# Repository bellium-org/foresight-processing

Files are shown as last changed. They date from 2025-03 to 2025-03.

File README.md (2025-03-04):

# Foresight Processing

## Overview
The processing board is responsible for the main processing of the vibration analysis. On board is the ATmega328pb microcontroller, RFM95W LoRa transceiver and ADXL362 accelerometer. In addition there is a NMOS low side switch to turn of the RFM95W and ADXL362 when they are not needed to save power consumption.

## Table of Contents

- [Hardware Setup](#hardware-setup)
- [Imporant Notice](#important-notice)

### Hardware Setup

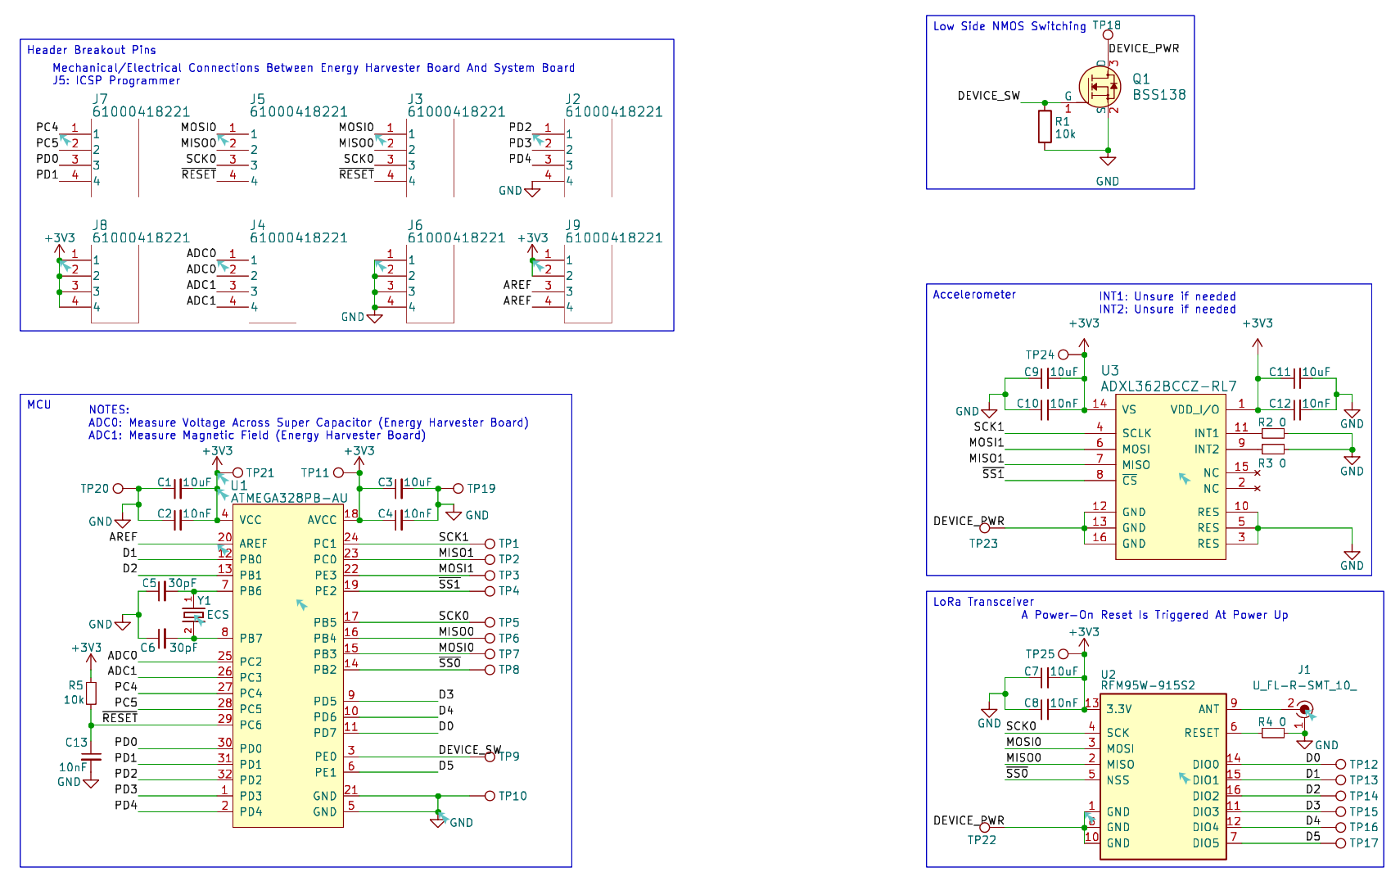
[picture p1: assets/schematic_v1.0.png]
Description of image


### Important Notice
- All required components used in this project can be located in the components folder. 
- To add these components into your workspace please follow the instructions from given from each of the individual components. 
- Ensure the digikey submodule is initialise and follow the README to set this up.

## Authors
- Nathan Nguyen

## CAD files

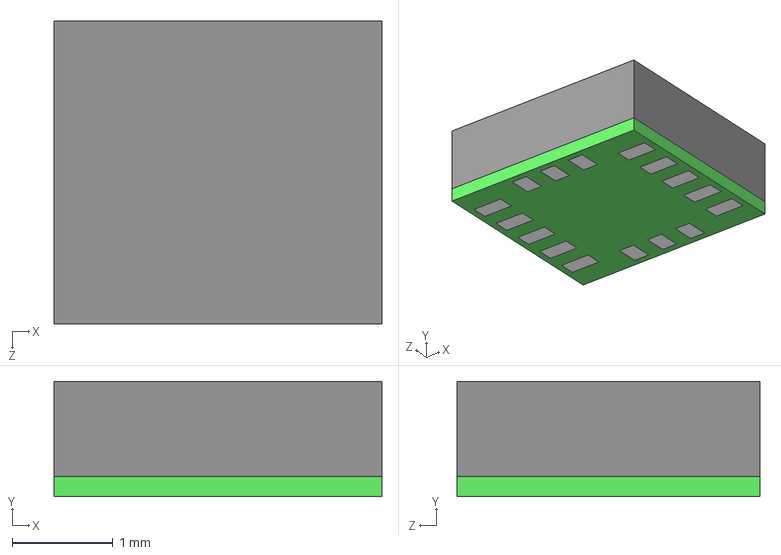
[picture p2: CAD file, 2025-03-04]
components/foresight/ADXL362BCCZ_RL7/ADXL362BCCZ-RL7.step
3.25 x 1.14 x 3.00 mm

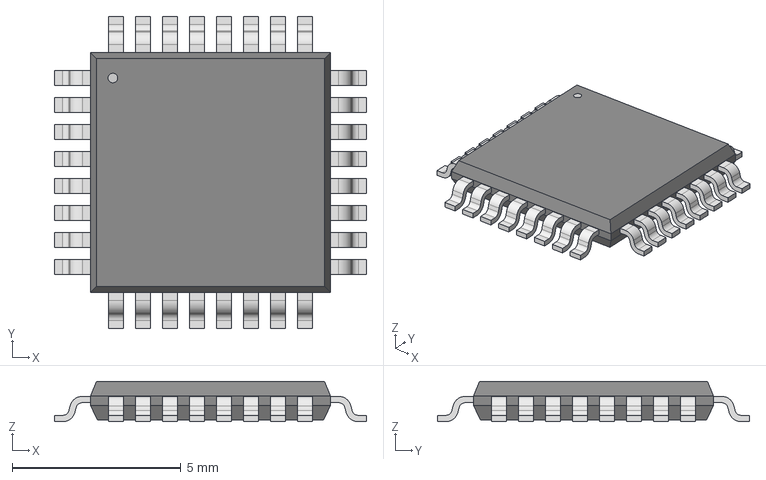
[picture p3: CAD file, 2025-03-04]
components/foresight/ATMEGA328P_AU/TQFP32_32A_MCH.step
9.25 x 9.25 x 1.20 mm

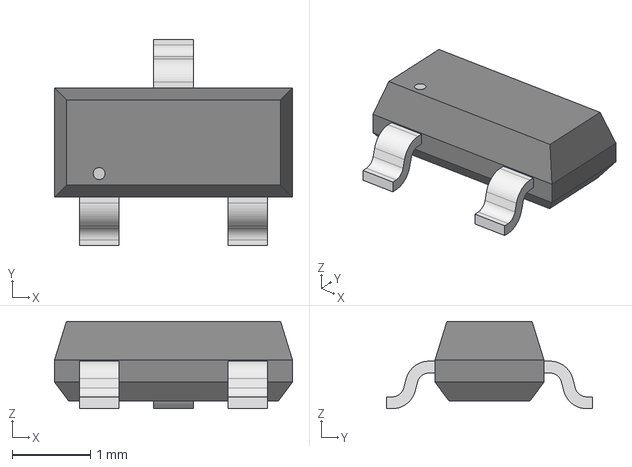
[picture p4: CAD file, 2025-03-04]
components/foresight/BSS138/SOT-23_3L_ONS.step
3.05 x 2.64 x 1.12 mm

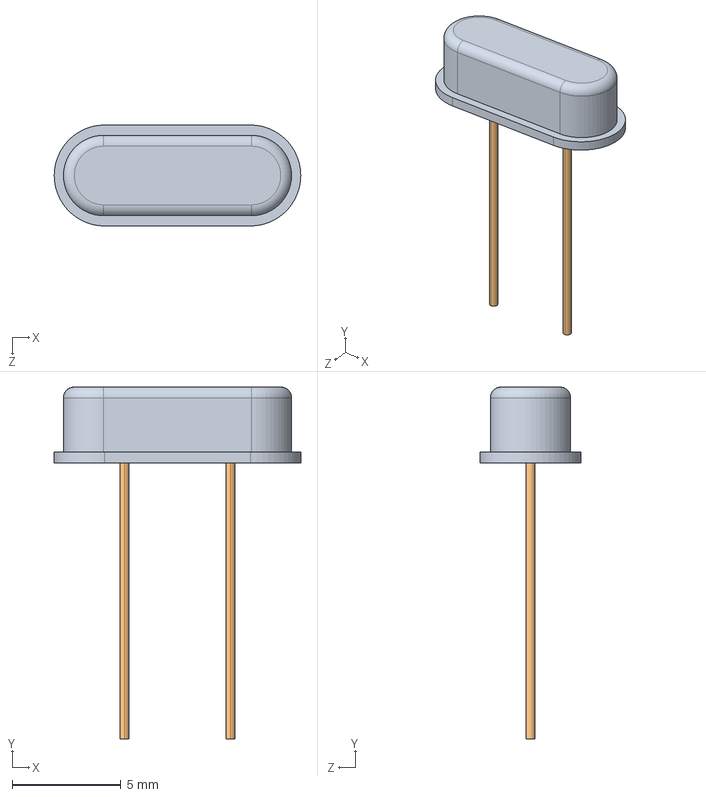
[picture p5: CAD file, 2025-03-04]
components/foresight/ECS_160_S_4/ECS-160-S-4.step
11.4 x 16.2 x 4.65 mm

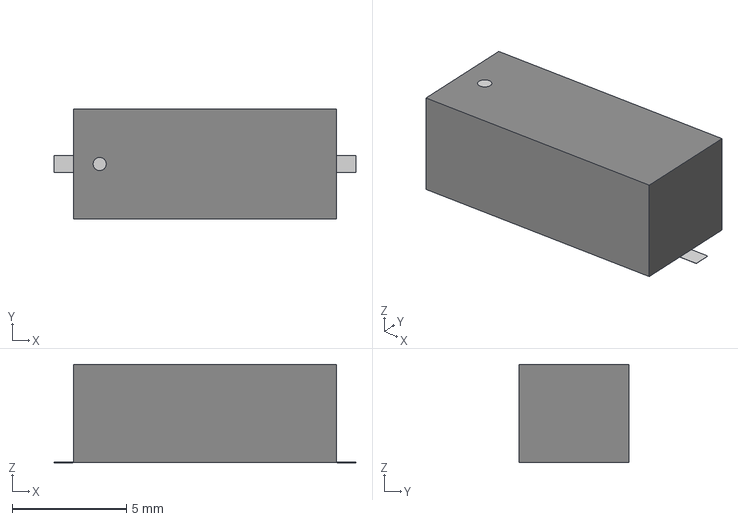
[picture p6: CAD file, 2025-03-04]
components/foresight/ECS_80_18_5PX_TR/CRYSTAL_ECS-80-18-5PX-TR_ECS.step
13.2 x 4.80 x 4.29 mm

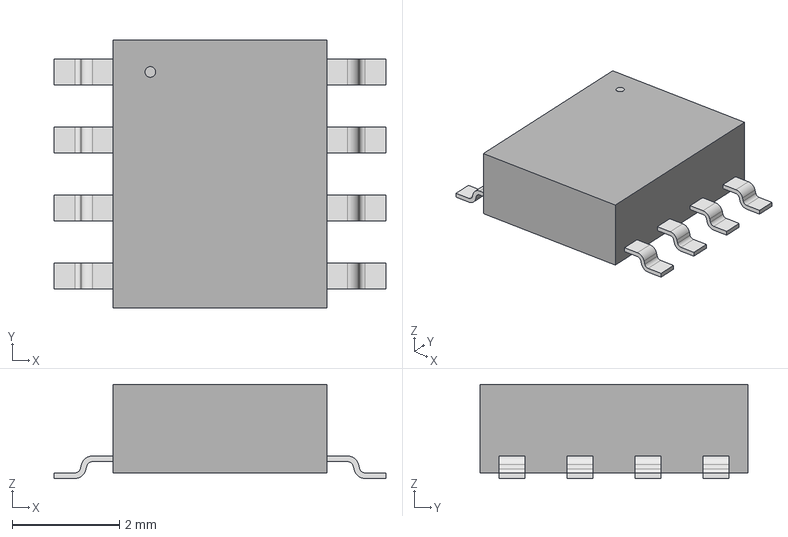
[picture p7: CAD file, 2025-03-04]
components/foresight/LT1763CS8_5_TRPBF/SO-8_S_LIT.step
6.20 x 5.00 x 1.75 mm

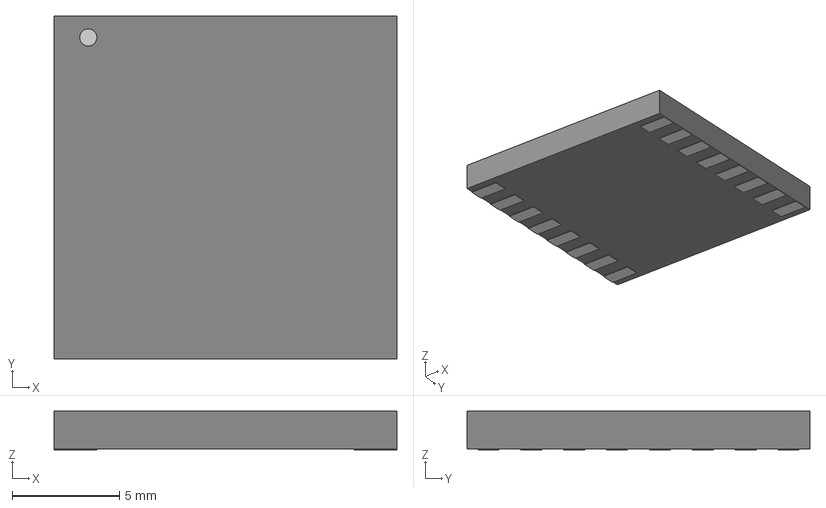
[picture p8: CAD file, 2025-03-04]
components/foresight/RFM95W_915S2/IC16_RFM95W-915S2_RFS.step
16.0 x 16.0 x 1.81 mm

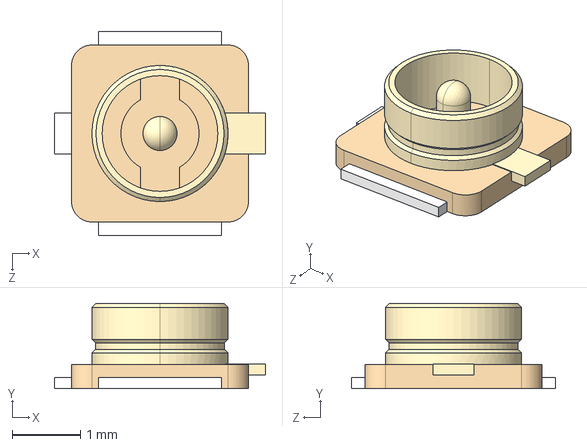
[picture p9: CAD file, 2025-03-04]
components/foresight/U_FL_R_SMT_10_/U.FL-R-SMT_10_.step
3.10 x 1.25 x 3.00 mm

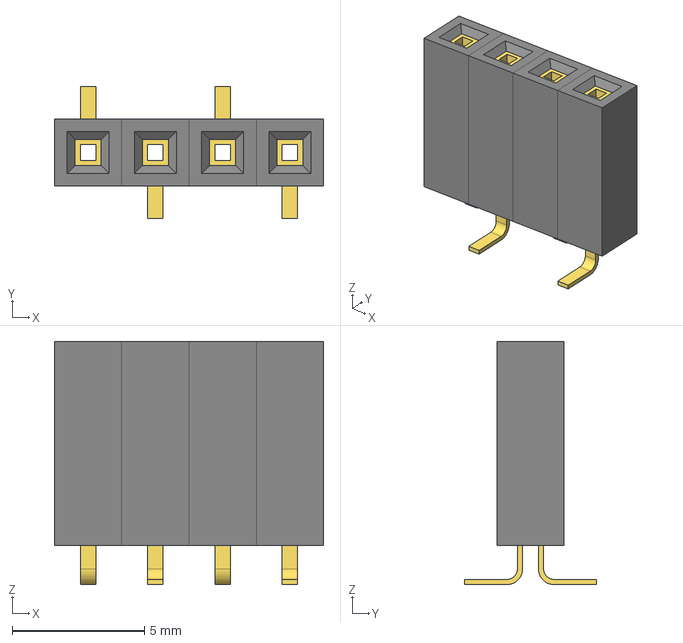
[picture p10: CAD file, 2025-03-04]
components/foresight/61000418221/61000418221_WRE.step
10.2 x 5.00 x 9.19 mm

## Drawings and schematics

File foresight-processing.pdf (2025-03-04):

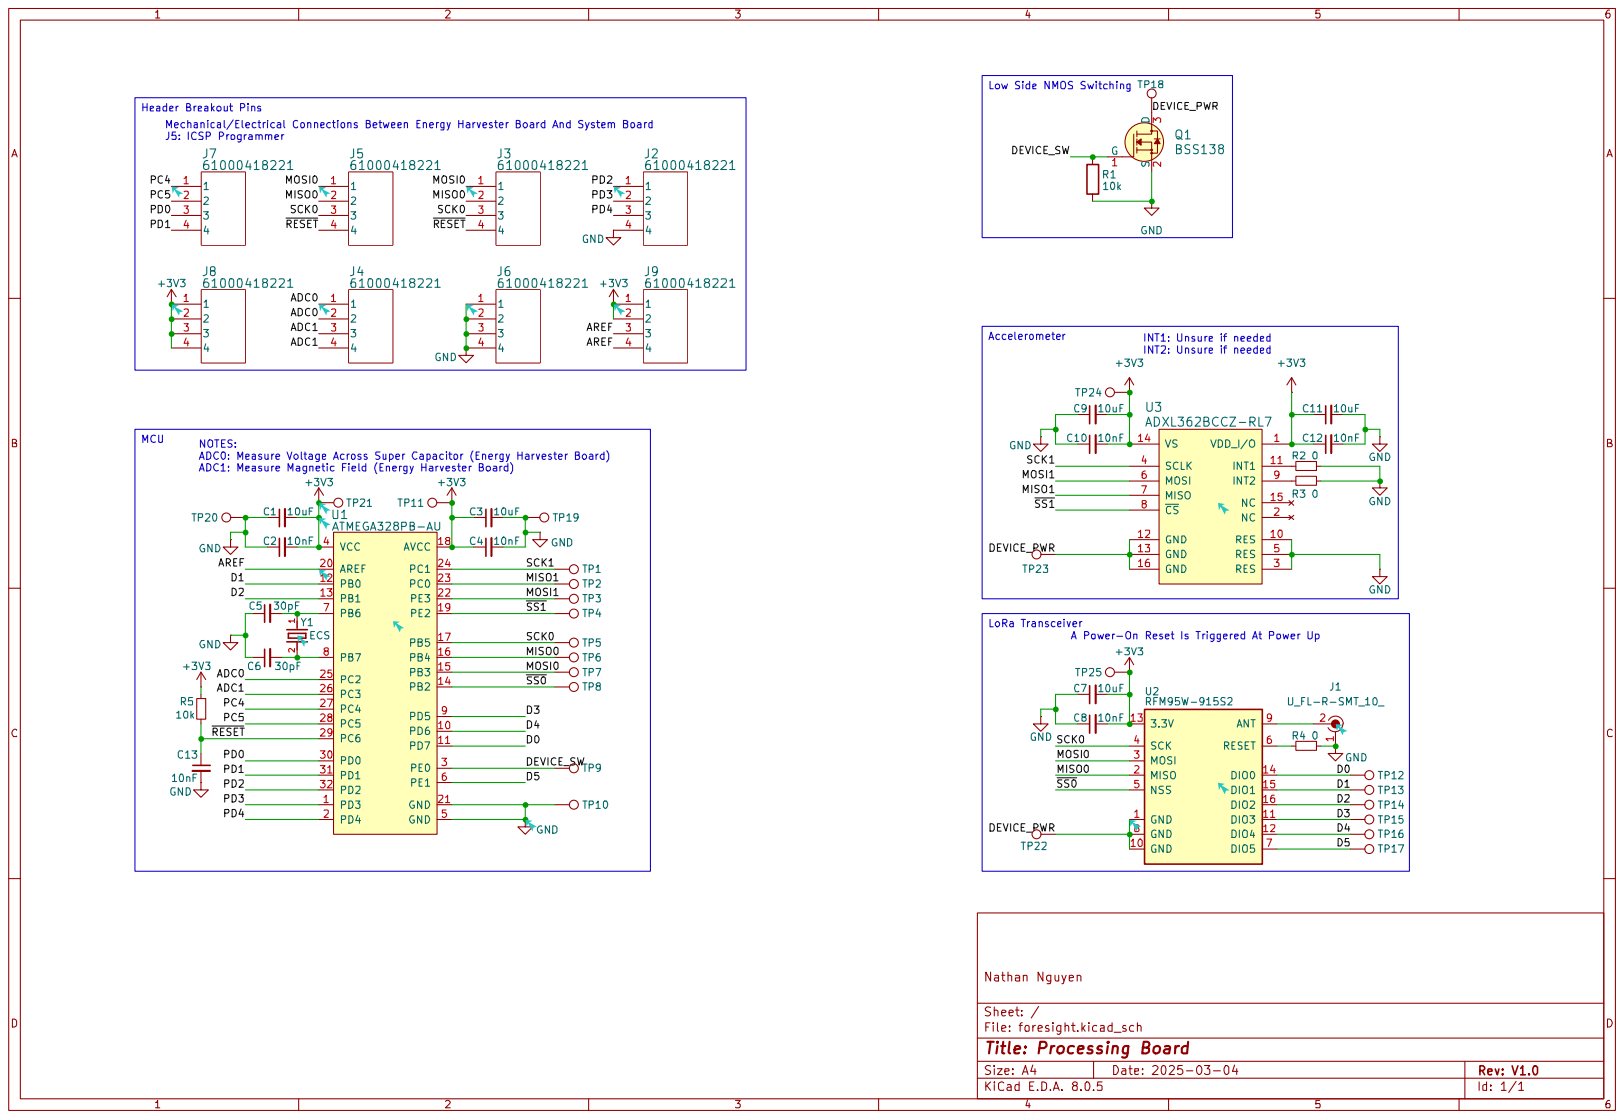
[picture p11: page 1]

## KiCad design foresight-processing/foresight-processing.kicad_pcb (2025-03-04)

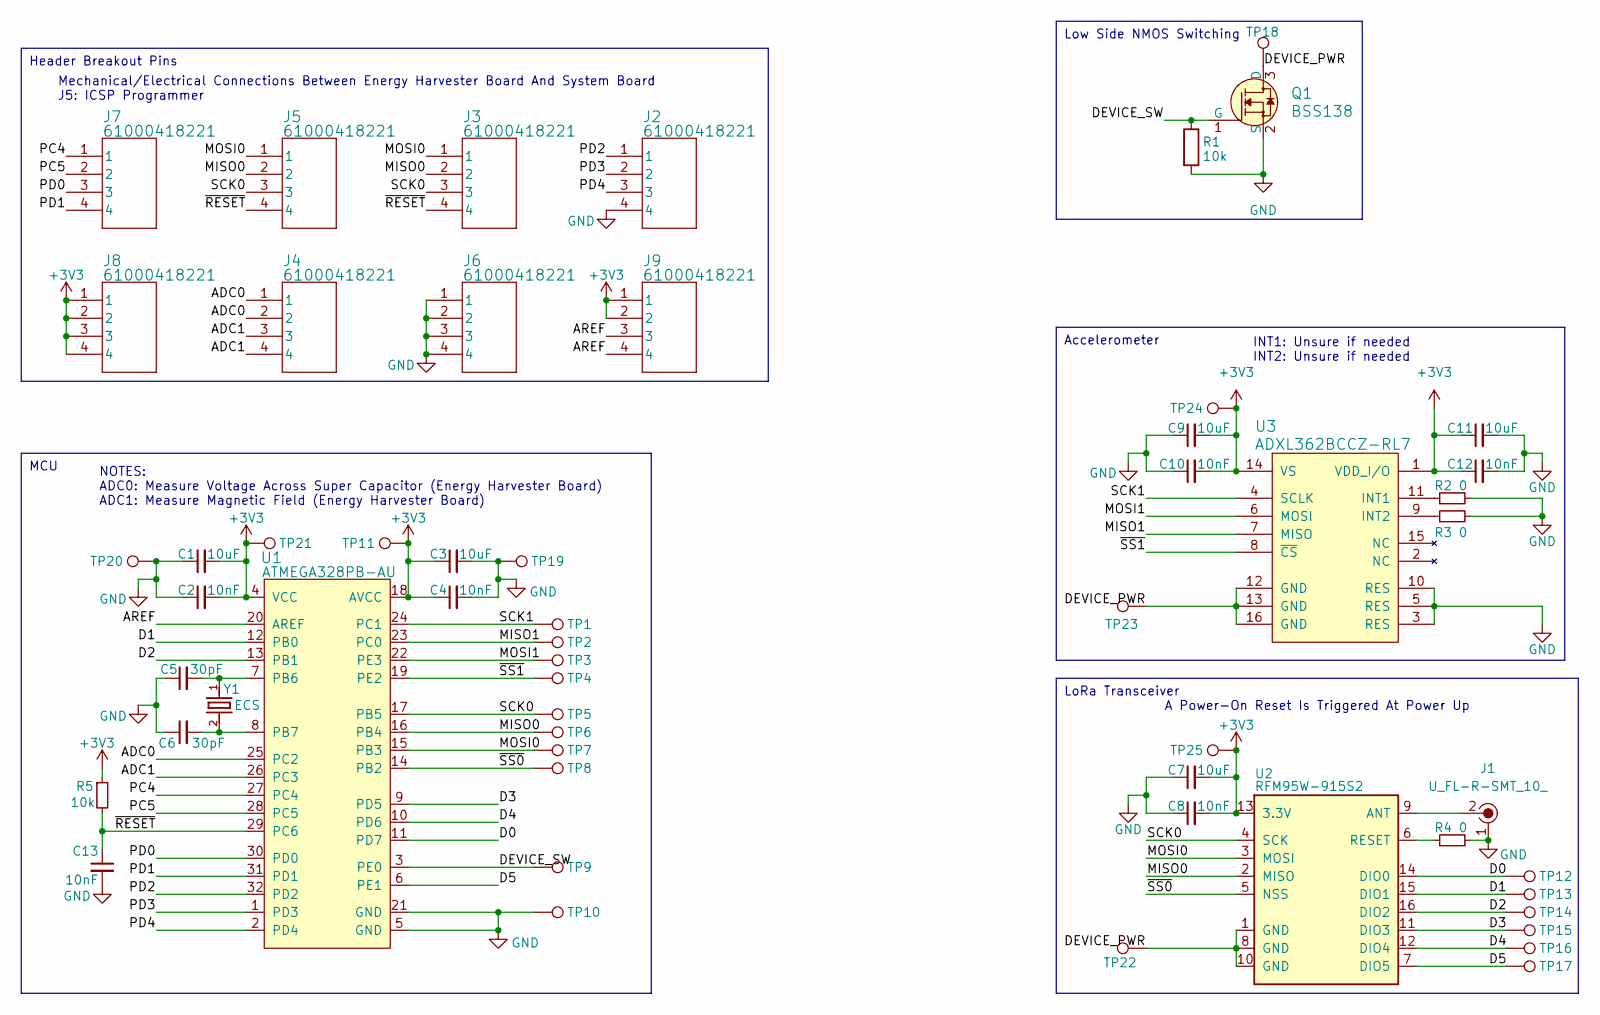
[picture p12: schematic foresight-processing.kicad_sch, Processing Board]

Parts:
C1, C3, C7, C9, C11: 10uF; C_0603_1608Metric
C2, C4, C8, C10, C12, C13: 10nF; C_0603_1608Metric
C5, C6: 30pF; C_0603_1608Metric
J1: U_FL-R-SMT_10_; Coax_Conn_U.FL; MPN U.FL-R-SMT(10); Digi-Key_PN H9161CT-ND
J2, J3, J4, J5, J6, J7, J8, J9: 61000418221; 61000418221_WRE
Q1: BSS138; SOT-23_3L_ONS; MPN BSS138; Digi-Key_PN BSS138CT-ND
R1, R5: 10k; R_0603_1608Metric
R2, R3, R4: 0; R_0603_1608Metric
TP1, TP2, TP3, TP4, TP5, TP6, TP7, TP8, TP9, TP10, TP11, TP12, TP13, TP14, TP15, TP16, TP17, TP18, TP19, TP20, TP21, TP22, TP23, TP24, TP25: TestPoint; TestPoint_Pad_D2.0mm
U1: ATMEGA328PB-AU; TQFP-32_7x7mm; MPN ATMEGA328PB-AU; Digi-Key_PN ATMEGA328PB-AU-ND
U2: RFM95W-915S2; HOPERF_RFM9XW_SMD
U3: ADXL362BCCZ-RL7; TFLGA-16_3x3.25mm; MPN ADXL362BCCZ-RL7; Digi-Key_PN ADXL362BCCZ-RL7CT-ND
Y1: ECS; CRYSTAL_ECS-80-18-5PX-TR_ECS

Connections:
+3V3: C1.2, C2.2, C3.1, C4.1, C7.2, C8.2, C9.2, C10.2, C11.1, C12.1, J8.1, J8.2, J8.3, J8.4, J9.1, J9.2, R5.1, TP11.1, TP21.1, TP24.1, TP25.1, U1.4 (VCC), U1.18 (AVCC), U2.13 (3.3V), U3.1 (VDD_I/O), U3.14 (VS)
/ADC0: J4.1, J4.2, U1.25 (PC2)
/ADC1: J4.3, J4.4, U1.26 (PC3)
/AREF: J9.3, J9.4, U1.20 (AREF)
/D0: TP12.1, U1.11 (PD7), U2.14 (DIO0)
/D1: TP13.1, U1.12 (PB0), U2.15 (DIO1)
/D2: TP14.1, U1.13 (PB1), U2.16 (DIO2)
/D3: TP15.1, U1.9 (PD5), U2.11 (DIO3)
/D4: TP16.1, U1.10 (PD6), U2.12 (DIO4)
/D5: TP17.1, U1.6 (PE1), U2.7 (DIO5)
/DEVICE_PWR: Q1.3 (D), TP18.1, TP22.1, TP23.1, U2.1 (GND), U2.8 (GND), U2.10 (GND), U3.12 (GND), U3.13 (GND), U3.16 (GND)
/DEVICE_SW: Q1.1 (G), R1.1, TP9.1, U1.3 (PE0)
/MISO0: J3.2, J5.2, TP6.1, U1.16 (PB4), U2.2 (MISO)
/MISO1: TP2.1, U1.23 (PC0), U3.7 (MISO)
/MOSI0: J3.1, J5.1, TP7.1, U1.15 (PB3), U2.3 (MOSI)
/MOSI1: TP3.1, U1.22 (PE3), U3.6 (MOSI)
/PC4: J7.1, U1.27 (PC4)
/PC5: J7.2, U1.28 (PC5)
/PD0: J7.3, U1.30 (PD0)
/PD1: J7.4, U1.31 (PD1)
/PD2: J2.1, U1.32 (PD2)
/PD3: J2.2, U1.1 (PD3)
/PD4: J2.3, U1.2 (PD4)
/SCK0: J3.3, J5.3, TP5.1, U1.17 (PB5), U2.4 (SCK)
/SCK1: TP1.1, U1.24 (PC1), U3.4 (SCLK)
/~RESET: C13.1, J3.4, J5.4, R5.2, U1.29 (PC6)
/~SS0: TP8.1, U1.14 (PB2), U2.5 (NSS)
/~SS1: TP4.1, U1.19 (PE2), U3.8 (~CS)
GND: C1.1, C2.1, C3.2, C4.2, C5.1, C6.1, C7.1, C8.1, C9.1, C10.1, C11.2, C12.2, C13.2, J1.1, J2.4, J6.1, J6.2, J6.3, J6.4, Q1.2 (S), R1.2, R2.2, R3.2, R4.2, TP10.1, TP19.1, TP20.1, U1.5 (GND), U1.21 (GND), U3.3 (RES), U3.5 (RES), U3.10 (RES)
unnamed: C5.2, U1.7 (PB6), Y1.1
unnamed: C6.2, U1.8 (PB7), Y1.2
unnamed: J1.2, U2.9 (ANT)
unnamed: R4.1, U2.6 (RESET)
unnamed: R2.1, U3.11 (INT1)
unnamed: R3.1, U3.9 (INT2)

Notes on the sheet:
MCU
Accelerometer
Low Side NMOS Switching
LoRa Transceiver
Header Breakout Pins
INT1: Unsure if needed INT2: Unsure if needed
Mechanical/Electrical Connections Between Energy Harvester Board And System Board J5: ICSP Programmer
NOTES: ADC0: Measure Voltage Across Super Capacitor (Energy Harvester Board) ADC1: Measure Magnetic Field (Energy Harvester Board)
A Power-On Reset Is Triggered At Power Up

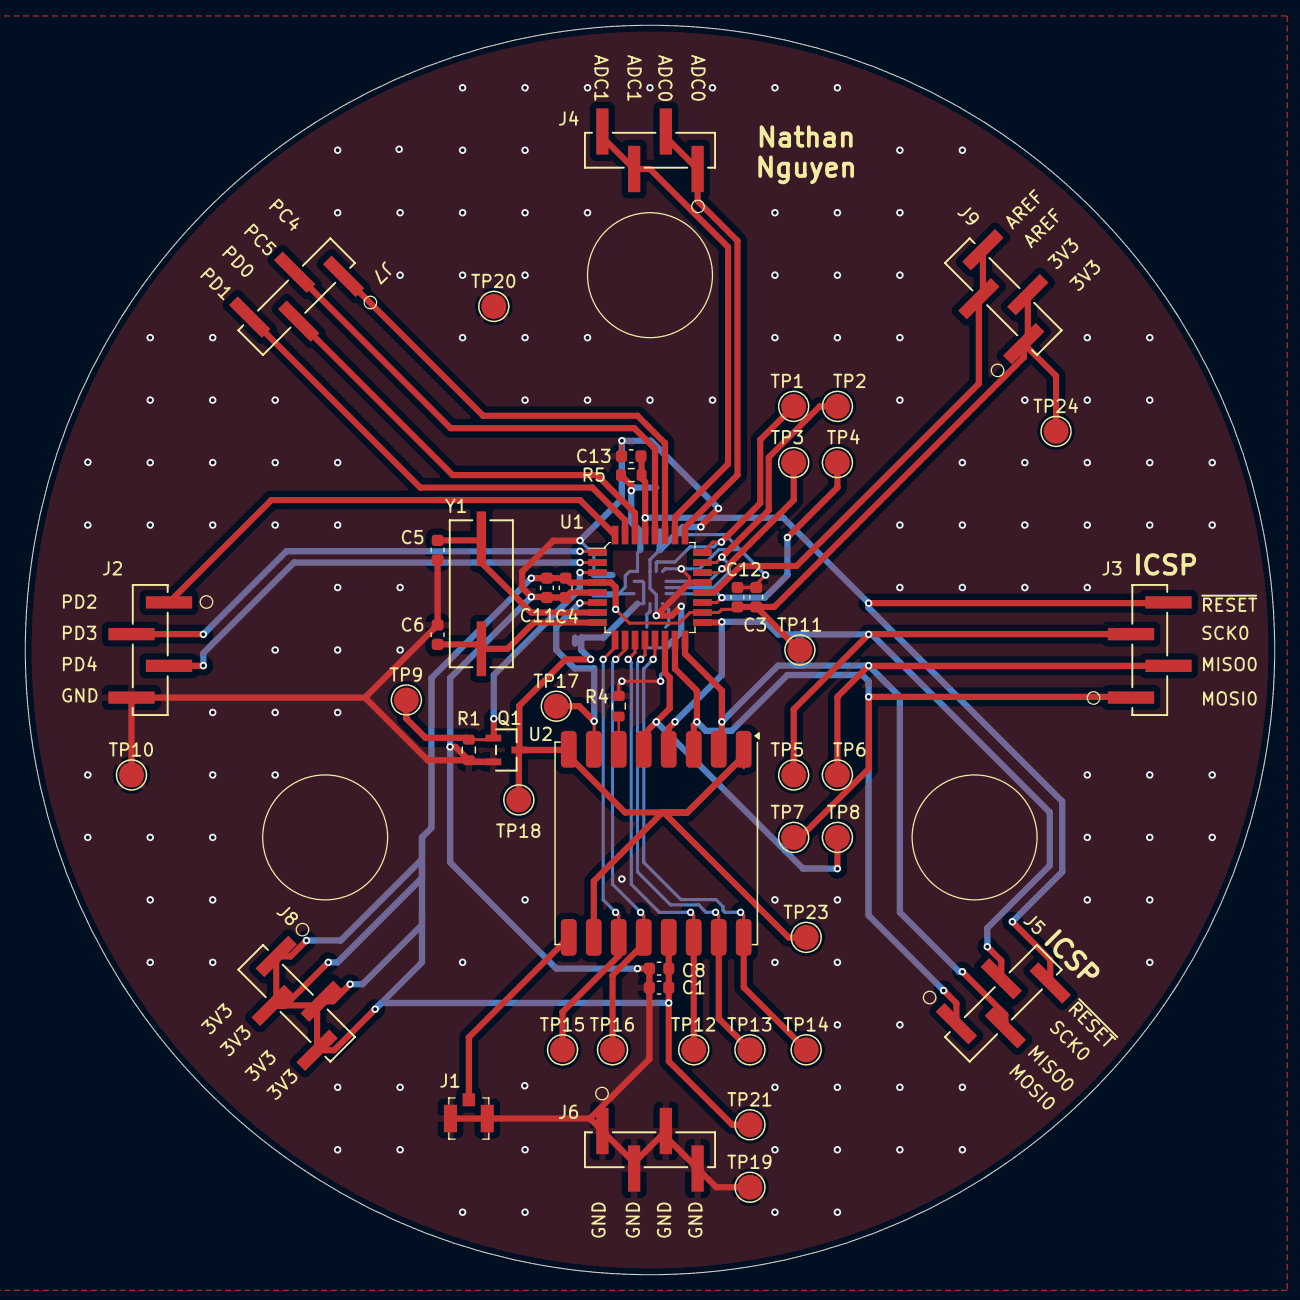
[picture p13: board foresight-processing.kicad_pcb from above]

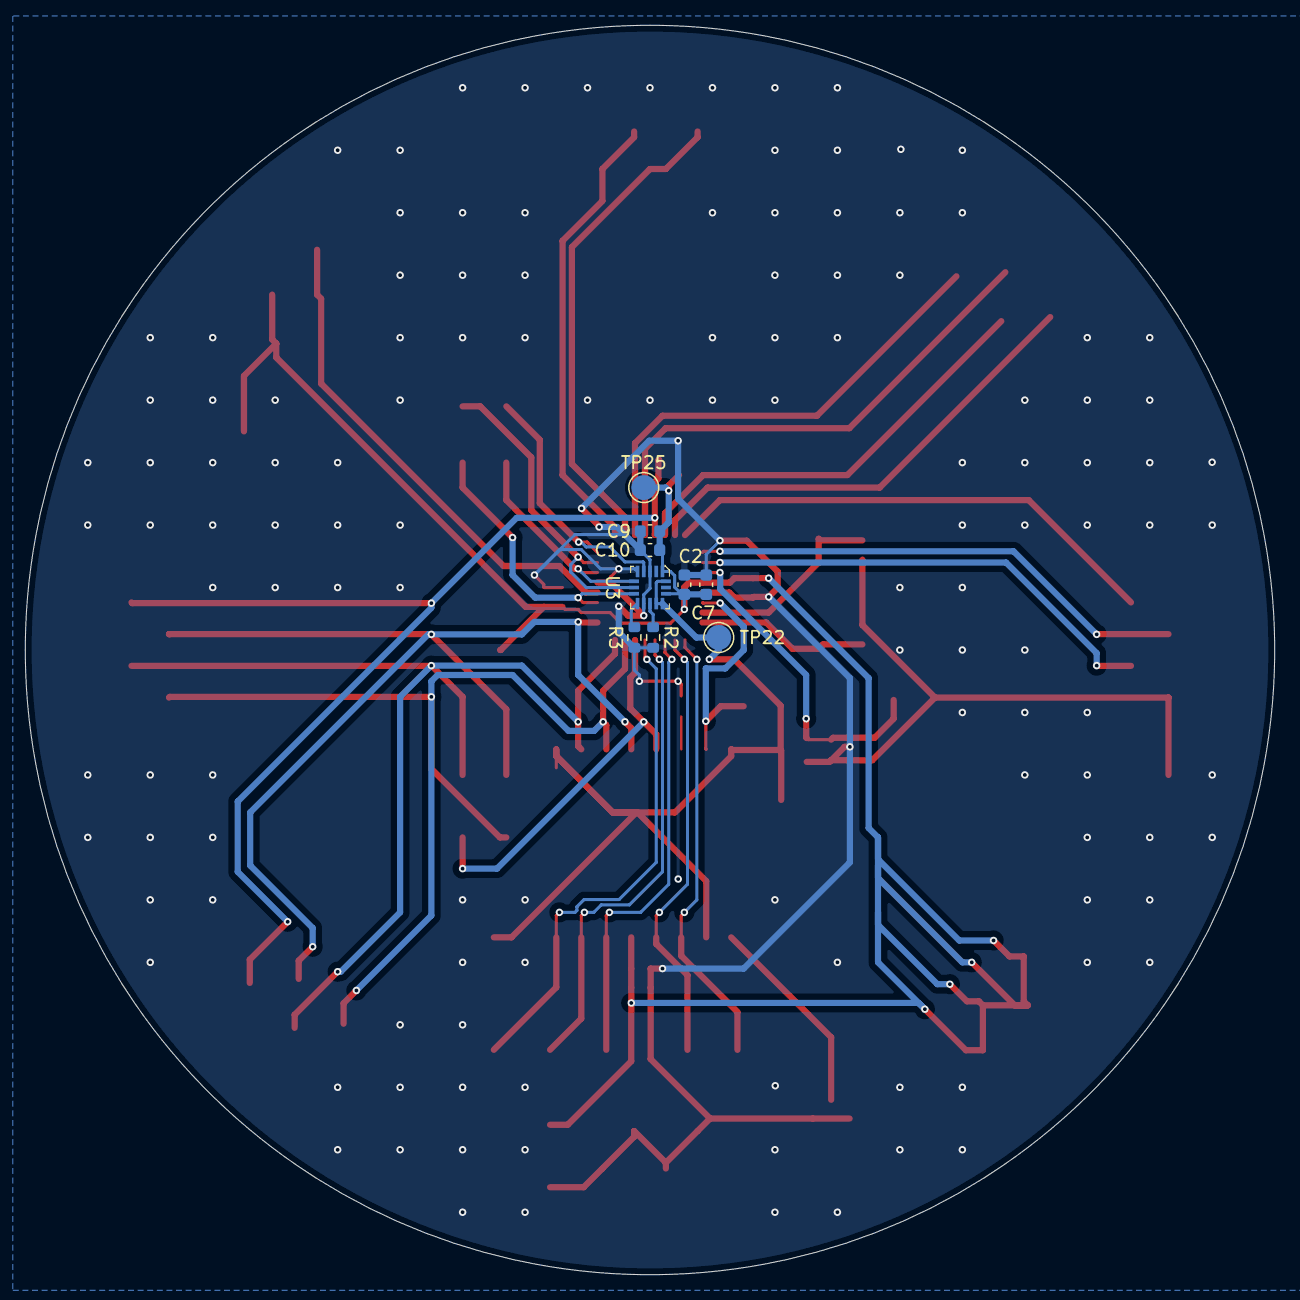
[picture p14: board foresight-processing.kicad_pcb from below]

Board: 2 copper layers, 100.0 x 100.0 mm, 57 parts (9 on the bottom side), 35 nets.
